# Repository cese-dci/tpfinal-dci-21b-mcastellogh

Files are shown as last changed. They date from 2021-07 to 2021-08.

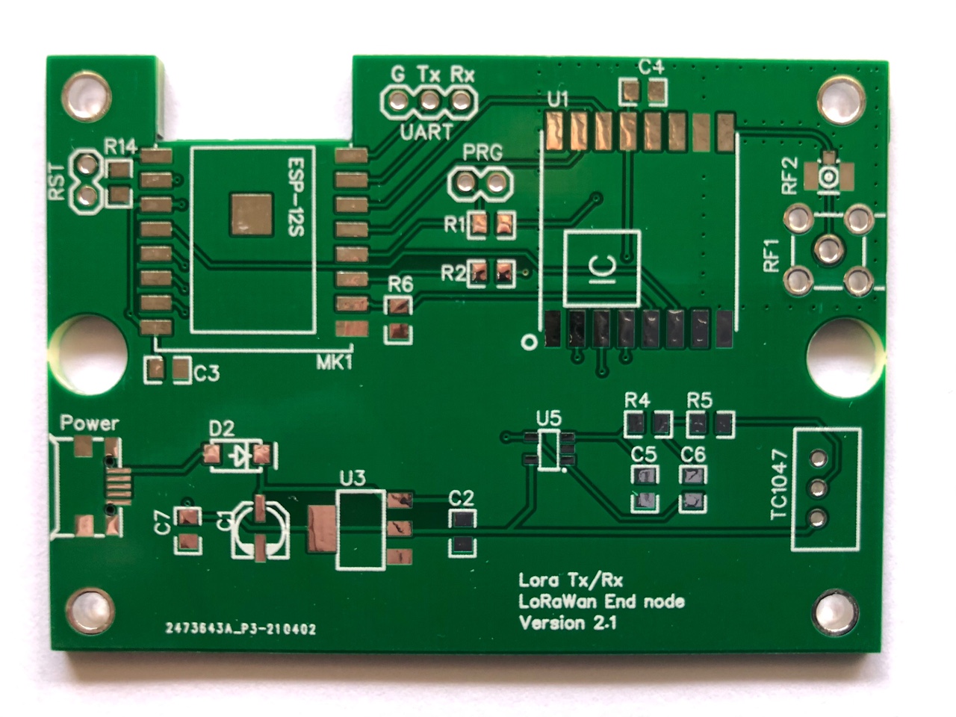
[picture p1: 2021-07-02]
doc/propuesta/pcb_A.jpg

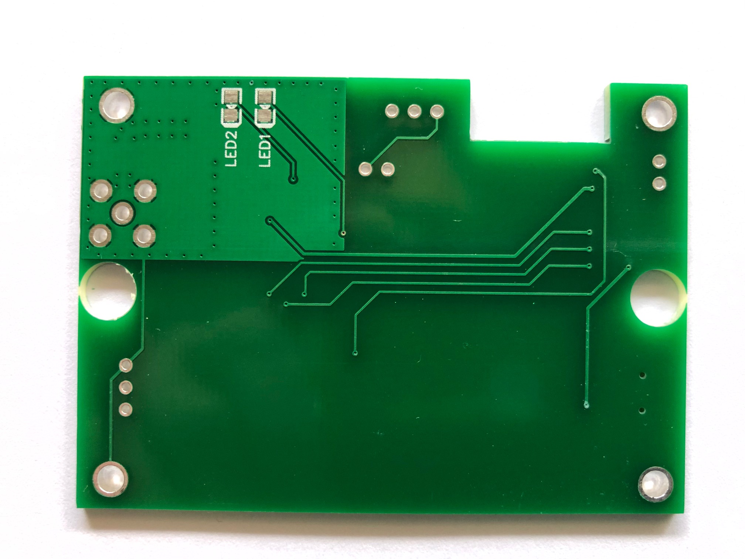
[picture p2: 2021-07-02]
doc/propuesta/pcb_b.jpg

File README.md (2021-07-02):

## Trabajo práctico final de la asignatura DCI ##
Este repositorio contiene el trabajo práctico final para la asignatura de Diseño de Circuitos Impresos de la carrera de posgrado de FIUBA.

* Autor: Marcelo Castello
* Título corto del trabajo:  LoRa End Device
* Descripción:  Implementación de dispositivo sensor de temperatiura con capa física LoRa/LoRaWAN con ESP8266

## Licencia de este trabajo ##
Licencia: [TAPR Open Hardware License](https://tapr.org/the-tapr-open-hardware-license)

[Enlace al archivo de texto de la misma](TAPR_Open_Hardware_License_v1.0.pdf)

## Estructura del TP FINAL ##

Se propone y se pide utilizar la siguiente estructura.

* doc: Toda la información sobre el circuito, principalmente de autoría o procesamiento propio. Por ejemplo:
  * Notas de ingeniería propias.
  * Notas de aplicación propias.
  * Estudios previos, estado del arte, resumen de las investigaciones.
  * Notas con cálculos.
  * Dibujos adicionales.
  * Fotos de los prototipos.
  * Presupuestos, cotizaciones.
* info: Toda la iformación recolectada, principalmente de terceros, como por ejemplo:
  * Hojas de datos.
  * Notas de aplicación.
  * Info de productos comerciales.
  * Info en internet.
* pcb: Archivos de diseño esquemático y pcb.

Dependiendo la magnitud del proyecto, tendremos más o menos información en estos directorios. 
Revisar los README.md en cada directorio para conocer las pautas de cada uno para este TP.

NOTA: El alumno puede y debe borrar de este archivo todo lo que considere necesario, por ejemplo las aclaraciones del docente y esta misma nota.

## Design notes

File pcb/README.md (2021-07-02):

## Archivos Kicad ##

En este directorio se incluyen:

* Archivos de proyecto.
* Esquemático.
* PCB.
* Modelos  3D.
* Bibliotecas de símbolos y huellas externas (incluídos en el directorio [libs](libs))

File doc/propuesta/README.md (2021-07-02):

## Propuesta ##
Se propone la realización de un pcb para un dispositivo tipo end-node para LoRaWAN.
El objetivo es diseñar un PCB aplicando buenas prácticas tanto para la realización del esquemático como para el ruteo de las pistas. También se pondrá especial interés en el ruteo de la línea de transmisión desde la salida de RF del RFM95 hasta los conectores de la antena.

El circuito está basado en dos módulos principales:
- Módulo con microcontrolador ESP12S.
- Módulo radio LoRa RFM95W.
Además el circuito implementa un filtro de segundo órden tipo Sallen-Key para la entrada analógica, donde se conecta un sensor de temperatura TC1047A.

El fimrware para su  funcionamiento como end-device LoRaWAN, está basado en la librería de IBM LMIC (LoraMac in C).\
Más información en los siguientes links:\
 https://github.com/matthijskooijman/arduino-lmic \
 https://github.com/JhonControl/ESP8266-LoRa-RFM95

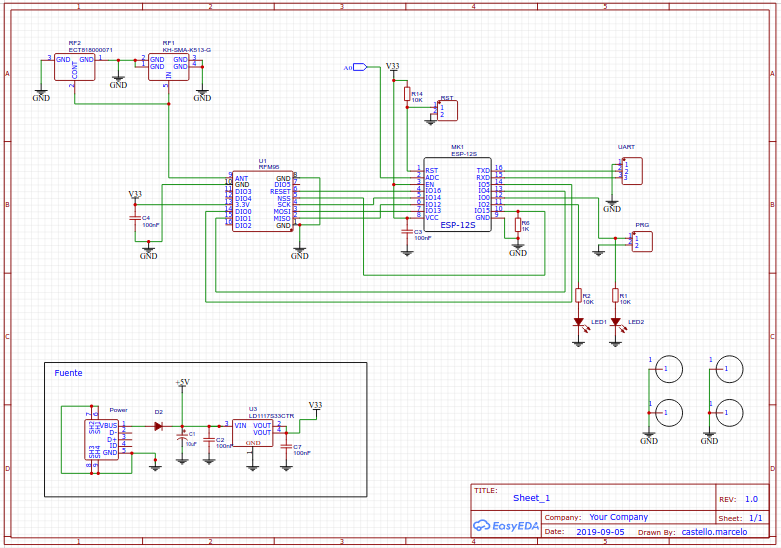
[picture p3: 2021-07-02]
doc/propuesta/Esquematico_A.png

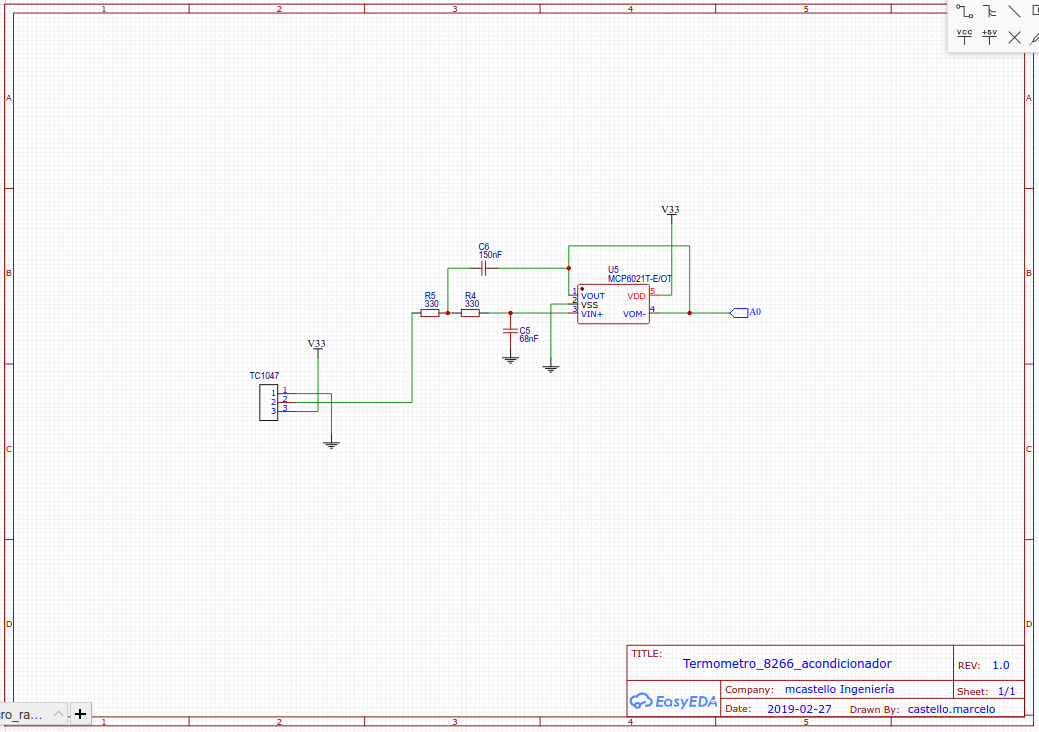
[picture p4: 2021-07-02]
doc/propuesta/Esquematico_B.png

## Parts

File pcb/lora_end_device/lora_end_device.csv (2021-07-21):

Reference | Value | Footprint | Datasheet | AVAILABILITY | DESCRIPTION | MANUFACTURER | MP | PACKAGE | PRICE | STANDARD | PARTREV | PROD_ID
R2 | 330 | Resistor_SMD:R_0805_2012Metric | ~
R1 | 330 | Resistor_SMD:R_0805_2012Metric | ~
C3 | 68nF | Capacitor_SMD:C_0805_2012Metric | ~
C2 | 150nF | Capacitor_SMD:C_0805_2012Metric | ~
C4 | 100nF | Capacitor_SMD:C_0805_2012Metric | ~
C5 | 100nF | Capacitor_SMD:C_0805_2012Metric | ~
U1 | TC1047A | Package_TO_SOT_SMD:SOT-23 | http://ww1.microchip.com/downloads/en/DeviceDoc/21498D.pdf
U3 | LD1117 | Package_TO_SOT_SMD:SOT-223-3_TabPin2 | http://www.st.com/st-web-ui/static/active/en/resource/technical/document/datasheet/CD00000544.pdf
C1 | 10uF | Capacitor_SMD:CP_Elec_3x5.3 | ~
J2 | UFL | RFUFL2:HRS_U.FL-R-SMT-1(10) | https://www.farnell.com/datasheets/2691132.pdf | Good | U.FL Series 6 Ghz 50 Ohm Ultra-small SMT Coaxial Cable Receptacle | Hirose | U.FL-R-SMT-1_10_ | None | 0.71 USD | Manufacturer Recommendation
R6 | 10K | Resistor_SMD:R_0805_2012Metric | ~
J3 | SMA | RFSMA:AMPHENOL_132203RP | https://ar.mouser.com/datasheet/2/18/1/amph_s_a0001368065_1-2260743.pdf |  |  | AMPHENOL CONEXX |  |  |  | Manufacturer recommendations | C
U4 | RFM95W | RF_Module:HOPERF_RFM9XW_SMD | https://www.hoperf.com/data/upload/portal/20181127/5bfcbea20e9ef.pdf
J4 | UART | Connector_PinHeader_2.54mm:PinHeader_1x03_P2.54mm_Vertical | ~
J5 | Reset | Connector_PinHeader_2.54mm:PinHeader_1x02_P2.54mm_Vertical | ~
D3 | Led Tx | LED_SMD:LED_0805_2012Metric_Castellated | ~
D2 | Led Rx | LED_SMD:LED_0805_2012Metric_Castellated | ~
J6 | PRG | Connector_PinHeader_2.54mm:PinHeader_1x02_P2.54mm_Vertical | ~
C6 | 100nF | Capacitor_SMD:C_0805_2012Metric | ~
C7 | 100nF | Capacitor_SMD:C_0805_2012Metric | ~
R5 | 10K | Resistor_SMD:R_0805_2012Metric | ~
R4 | 10K | Resistor_SMD:R_0805_2012Metric | ~
R3 | 1K | Resistor_SMD:R_0805_2012Metric | ~
J1 | USB_B_Micro | Connector_USB:USB_Mini-B_Lumberg_2486_01_Horizontal | ~
D1 | 1N4007 | Diode_SMD:D_1206_3216Metric | http://www.vishay.com/docs/88503/1n4001.pdf
H1 | MountingHole | MountingHole:MountingHole_3.2mm_M3 | ~
H3 | MountingHole | MountingHole:MountingHole_3.2mm_M3 | ~
H2 | MountingHole | MountingHole:MountingHole_3.2mm_M3 | ~
H4 | MountingHole | MountingHole:MountingHole_3.2mm_M3 | ~
U2 | MCP6021 | mcp6021:SOT23-5 | http://ww1.microchip.com/downloads/en/devicedoc/20001685e.pdf |  |  |  |  |  |  |  |  | IC-12504
U5 | ESP-12S | esp12s:ESP-12S | https://docs.ai-thinker.com/_media/esp8266/docs/esp-12s_product_specification_en.pdf |  |  |  |  |  |  |  |  | IC-14115

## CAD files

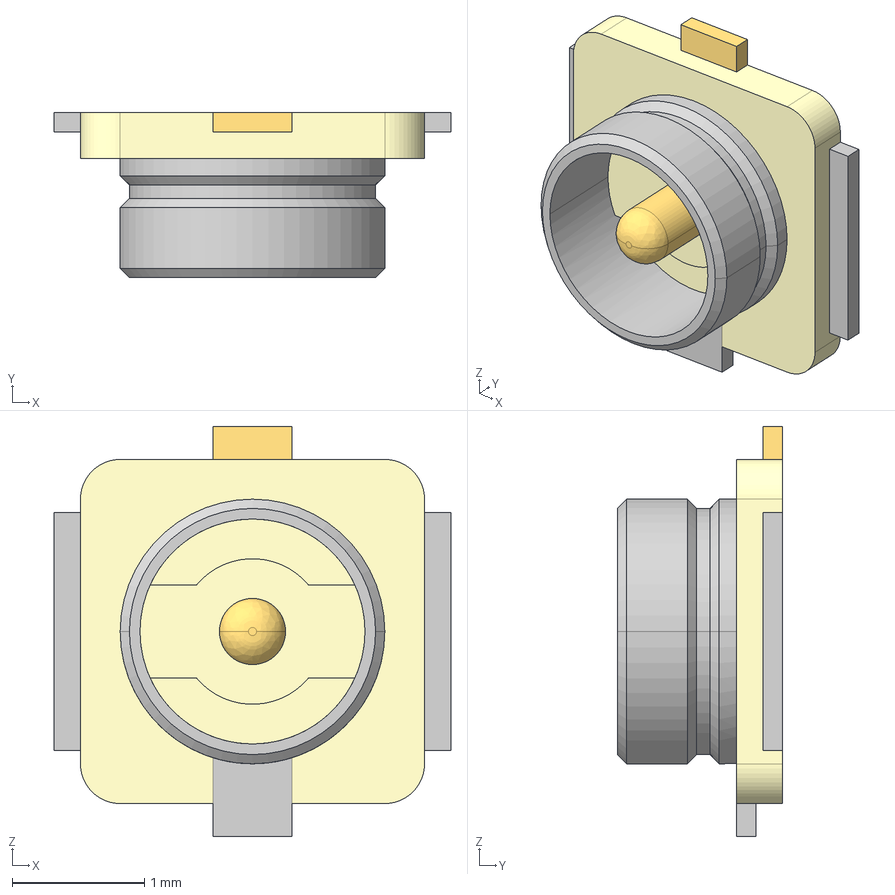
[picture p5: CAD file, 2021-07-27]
pcb/3dmodels/u_fl-r-smt-1_10_.stp
3.00 x 1.25 x 3.10 mm

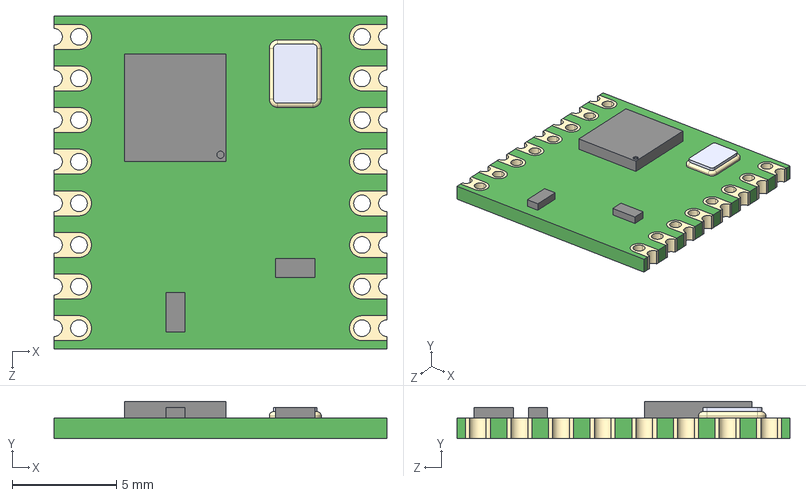
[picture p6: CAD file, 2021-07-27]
pcb/3dmodels/RFM95W-915S2--3DModel-STEP-56544.STEP
16.0 x 1.80 x 16.0 mm

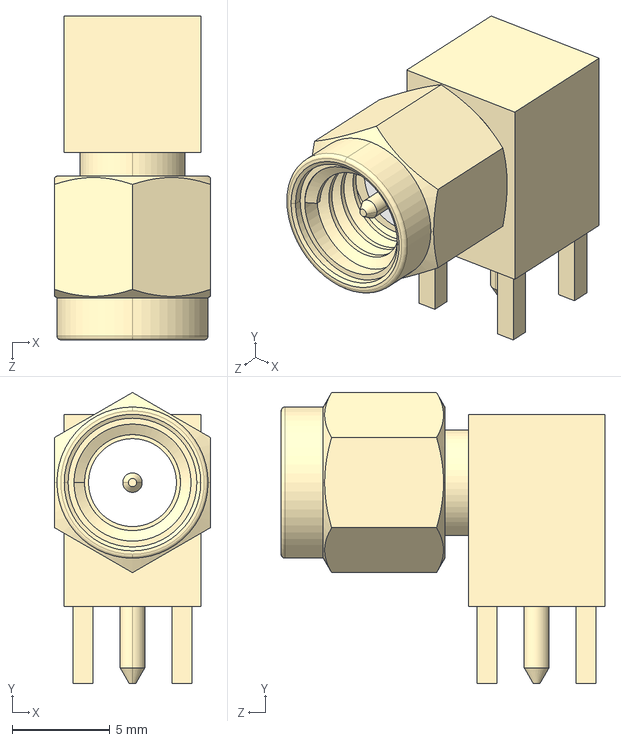
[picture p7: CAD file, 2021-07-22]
pcb/3dmodels/901-9894-RFX--3DModel-STEP-56544.STEP
8.00 x 14.9 x 16.6 mm

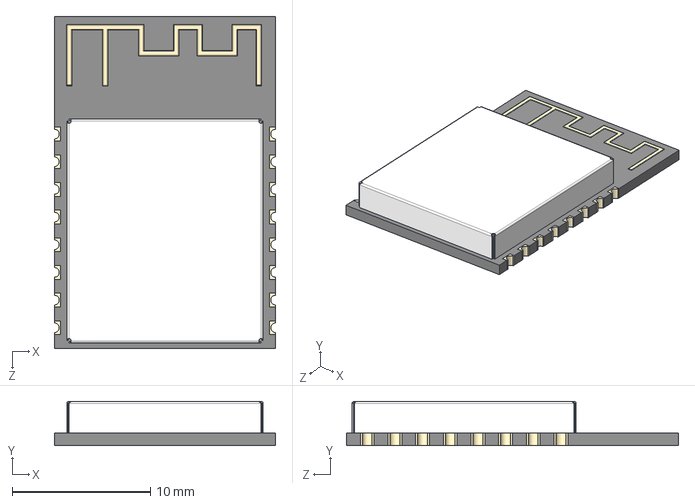
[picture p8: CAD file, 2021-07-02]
pcb/3dmodels/ESP-12S--3DModel-STEP-56544.STEP
16.0 x 3.20 x 24.0 mm

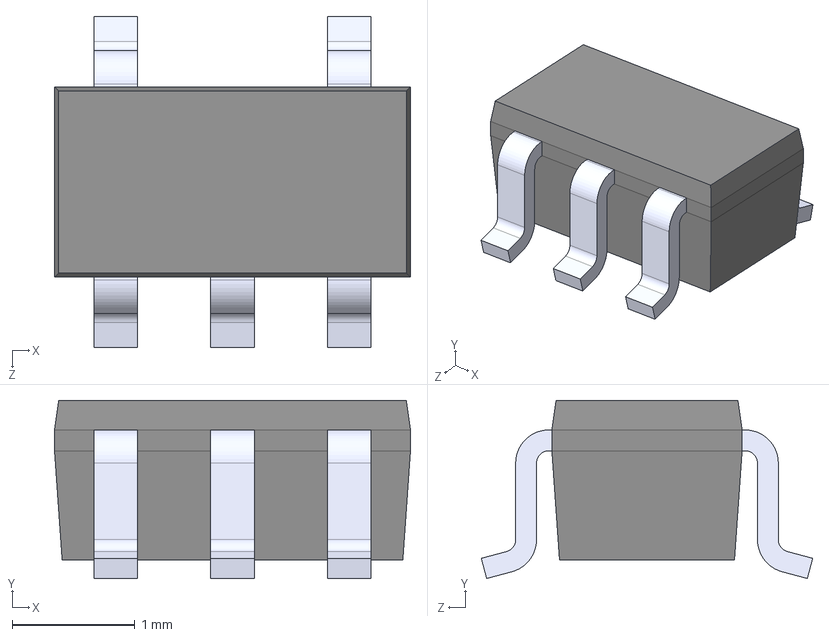
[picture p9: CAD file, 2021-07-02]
pcb/3dmodels/MCP6021.STEP
2.90 x 1.45 x 2.70 mm

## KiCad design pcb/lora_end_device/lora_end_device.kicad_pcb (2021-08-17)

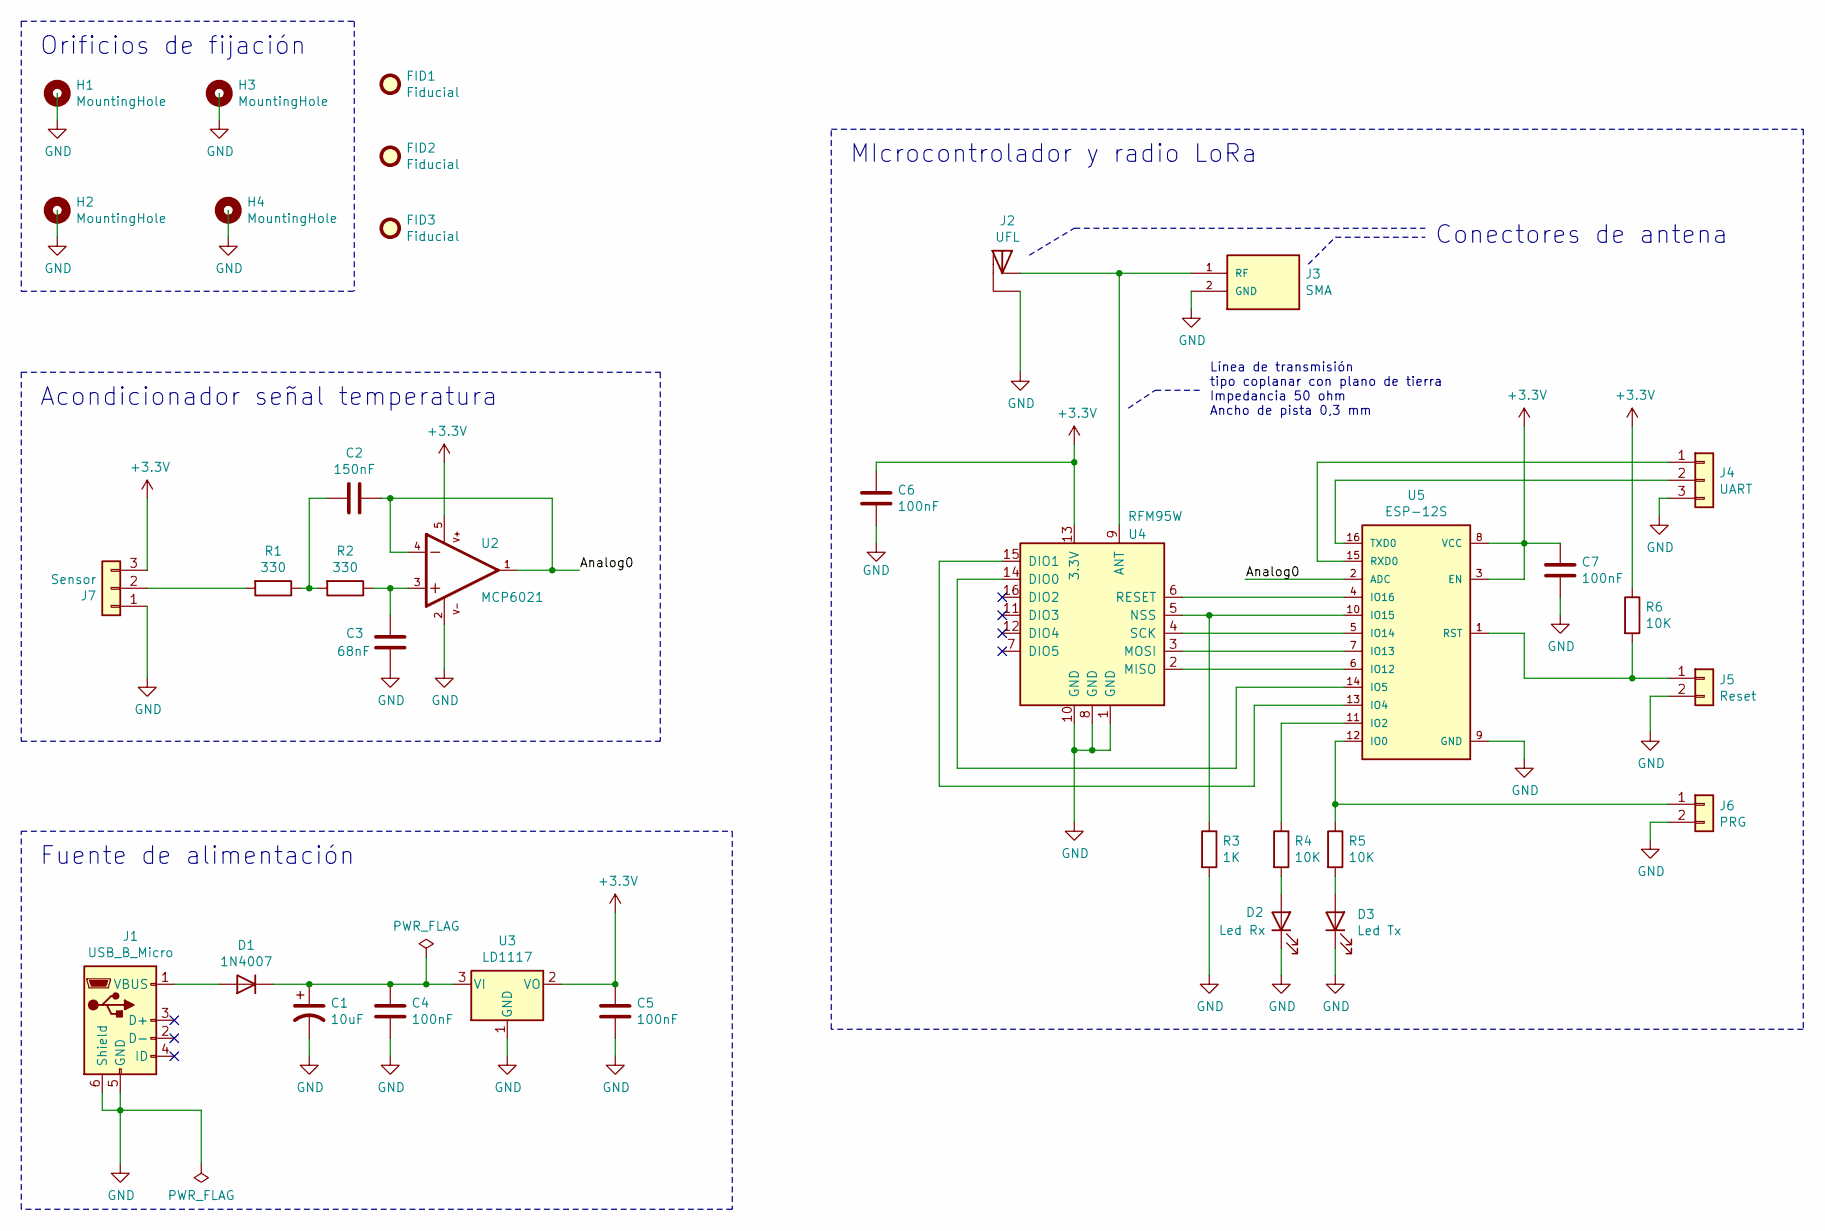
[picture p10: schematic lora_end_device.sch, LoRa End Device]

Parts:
C1: 10uF; CP_Elec_3x5.3
C2: 150nF; C_0805_2012Metric
C3: 68nF; C_0805_2012Metric
C4, C5, C6, C7: 100nF; C_0805_2012Metric
D1: 1N4007; D_1206_3216Metric
D2: Led Rx; LED_0805_2012Metric_Castellated; digikey# 350-4358-2-ND
D3: Led Tx; LED_0805_2012Metric_Castellated; digikey# 3372-0805RBD0070S01TR-ND
FID1, FID2, FID3: Fiducial; Fiducial_0.75mm_Mask1.5mm
H1, H2, H3, H4: MountingHole; MountingHole_2.5mm_Pad
J1: USB_B_Micro; USB_Mini-B_Lumberg_2486_01_Horizontal; digikey# 2057-MCR-B-S-RA-TSMT-NP-CS4-T/R-ND
J2: UFL; HRS_U.FL-R-SMT-1(10); digikey# CONUFL001-SMD-TTR-ND
J3: SMA; AMPHENOL_132203RP; PARTREV C; digikey# 732-13840-ND
J4: UART; PinHeader_1x03_P2.54mm_Vertical; digikey 2073-BC020-03-A-0200-0300-L-G-ND
J5: Reset; PinHeader_1x02_P2.54mm_Vertical; digikey 664-G800LF306018EU-ND
J6: PRG; PinHeader_1x02_P2.54mm_Vertical; digikey# 664-G800LF306018EU-ND
J7: Sensor; PinHeader_1x03_P2.54mm_Vertical; digikey# 2073-BC020-03-A-0200-0300-L-G-ND
R1, R2: 330; R_0805_2012Metric
R3: 1K; R_0805_2012Metric
R4, R5, R6: 10K; R_0805_2012Metric
U2: MCP6021; SOT23-5; digikey# MCP6021RT-E/OTTR-ND
U3: LD1117; SOT-223-3_TabPin2; digikey# 497-6447-2-ND
U4: RFM95W; HOPERF_RFM9XW_SMD; digikey# RFM95W-915S2-ND
U5: ESP-12S; digikey# ESP-12SRF-ND

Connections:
+3V3: C5.1, C6.1, C7.1, J7.3, R6.1, U2.5, U3.2 (VO), U4.13 (3.3V), U5.3 (EN), U5.8 (VCC)
/Analog0: C2.1, U2.1, U2.4, U5.2 (ADC)
GND: C1.2, C3.2, C4.2, C5.2, C6.2, C7.2, D2.1 (K), D3.1 (K), H1.1, H2.1, H3.1, H4.1, J1.5 (GND), J1.6 (Shield), J2.1, J3.2 (GND), J3.3, J3.4, J3.5, J4.3, J5.2, J6.2, J7.1, R3.2, U2.2, U3.1 (GND), U4.1 (GND), U4.8 (GND), U4.10 (GND), U5.9 (GND)
unnamed: C1.1, C4.1, D1.1 (K), U3.3 (VI)
unnamed: C2.2, R1.1, R2.2
unnamed: C3.1, R2.1, U2.3
unnamed: D1.2 (A), J1.1 (VBUS)
unnamed: D2.2 (A), R4.2
unnamed: D3.2 (A), R5.2
unnamed: J2.2, J3.1 (RF), U4.9 (ANT)
unnamed: J4.1, U5.15 (RXD0)
unnamed: J4.2, U5.16 (TXD0)
unnamed: J5.1, R6.2, U5.1 (RST)
unnamed: J6.1, R5.1, U5.12 (IO0)
unnamed: J7.2, R1.2
unnamed: R3.1, U4.5 (NSS), U5.10 (IO15)
unnamed: R4.1, U5.11 (IO2)
unnamed: U4.2 (MISO), U5.6 (IO12)
unnamed: U4.3 (MOSI), U5.7 (IO13)
unnamed: U4.4 (SCK), U5.5 (IO14)
unnamed: U4.6 (RESET), U5.4 (IO16)
unnamed: U4.14 (DIO0), U5.14 (IO5)
unnamed: U4.15 (DIO1), U5.13 (IO4)

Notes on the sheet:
Acondicionador señal temperatura
Fuente de alimentación
Conectores de antena
Orificios de fijación
MIcrocontrolador y radio LoRa
Línea de transmisión tipo coplanar con plano de tierra Impedancia 50 ohm Ancho de pista 0,3 mm

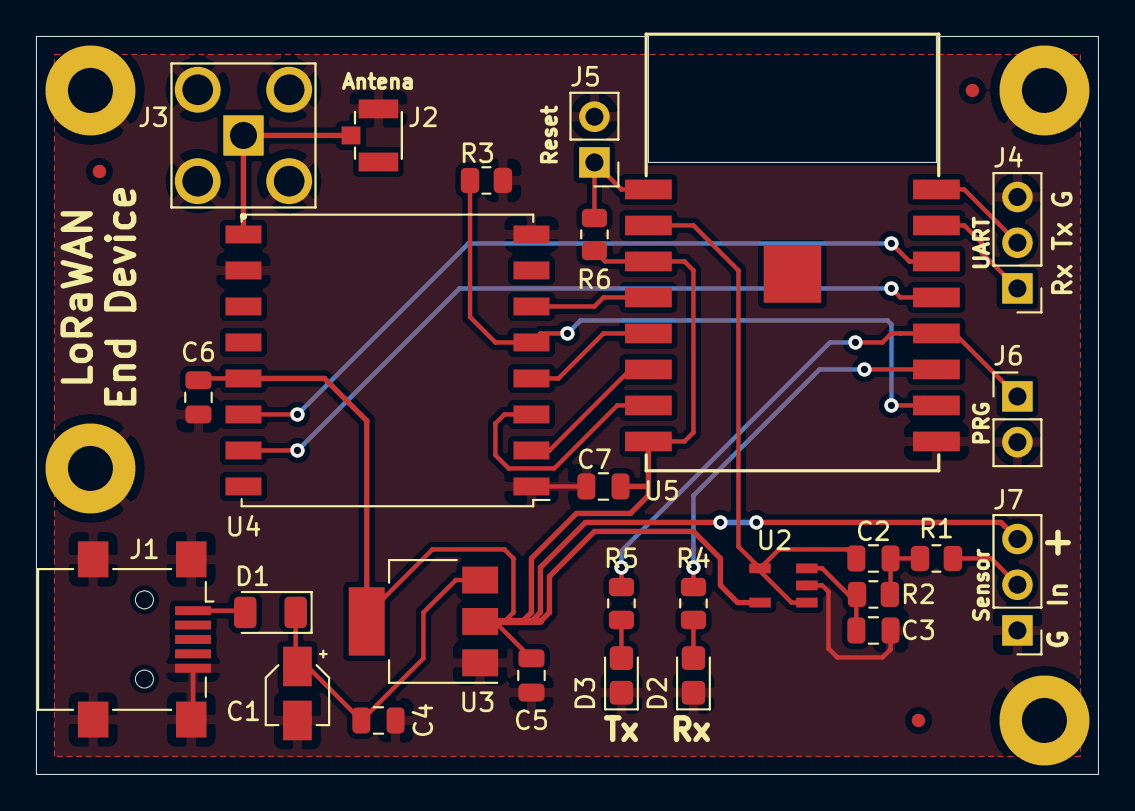
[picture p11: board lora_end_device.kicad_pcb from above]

Board: 2 copper layers, 59.0 x 41.0 mm, 34 parts (0 on the bottom side), 23 nets.

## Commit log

2021-07-02 primer commit
    [ESP-12S--3DModel-STEP-56544.STEP, MCP6021.STEP, lora_end_device.kicad_pcb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]
2021-07-05 fix bugs ERC
    [lora_end_device.sch]
2021-07-06 add asociaciones footprint, orificios fijacion
    [lora_end_device.sch]
2021-07-21 correcciones de sugerencias revisor
    [lora_end_device.csv, lora_end_device.sch]
2021-07-22 asociacion huellas, posicionamiento, borde
    [lora_end_device.sch]
2021-07-27 add 3d models
    [901-9894-RFX--3DModel-STEP-56544.STEP, RFM95W-915S2--3DModel-STEP-56544.STEP, lora_end_device.kicad_pcb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]
2021-07-27 reubicacion de U5 y U4
    [lora_end_device.kicad_pcb]
2021-07-27 reubicacion U4, U5 add cotas
    [lora_end_device.kicad_pcb]
2021-07-29 reubicación de conector SMA
    [lora_end_device.kicad_pcb, lora_end_device.sch]
2021-08-03 add digikey part number
    [lora_end_device.sch]
2021-08-10 add ruteo
    [lora_end_device-B_Cu.gbr, lora_end_device-B_Mask.gbr, lora_end_device-B_SilkS.gbr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]
2021-08-15 correcciones revisiones del docente
    [lora_end_device.kicad_pcb, lora_end_device.sch]
2021-08-17 Correcciones finales
    [lora_end_device.kicad_pcb]

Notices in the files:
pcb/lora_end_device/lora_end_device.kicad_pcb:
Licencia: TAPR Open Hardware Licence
